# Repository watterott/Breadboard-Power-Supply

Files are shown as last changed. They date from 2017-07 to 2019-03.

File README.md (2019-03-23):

# Breadboard Power Supply
Power supply for Breadboards.

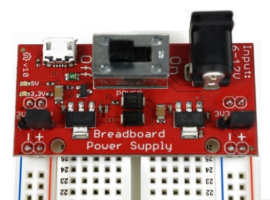
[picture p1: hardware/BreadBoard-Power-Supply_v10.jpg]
Breadboard Power Supply (5V/3.3V)


* Power Input: microUSB or 2.1mm DC jack
* 5V 800mA voltage regulator
* 3.3V 800mA voltage regulator
* 3.3V or 5V output selectable with jumper
* Open-Source and released under the [Creative Commons Attribution Share-Alike License](https://creativecommons.org/licenses/by-sa/4.0/).
* **[Documentation on learn.watterott.com](https://learn.watterott.com)**

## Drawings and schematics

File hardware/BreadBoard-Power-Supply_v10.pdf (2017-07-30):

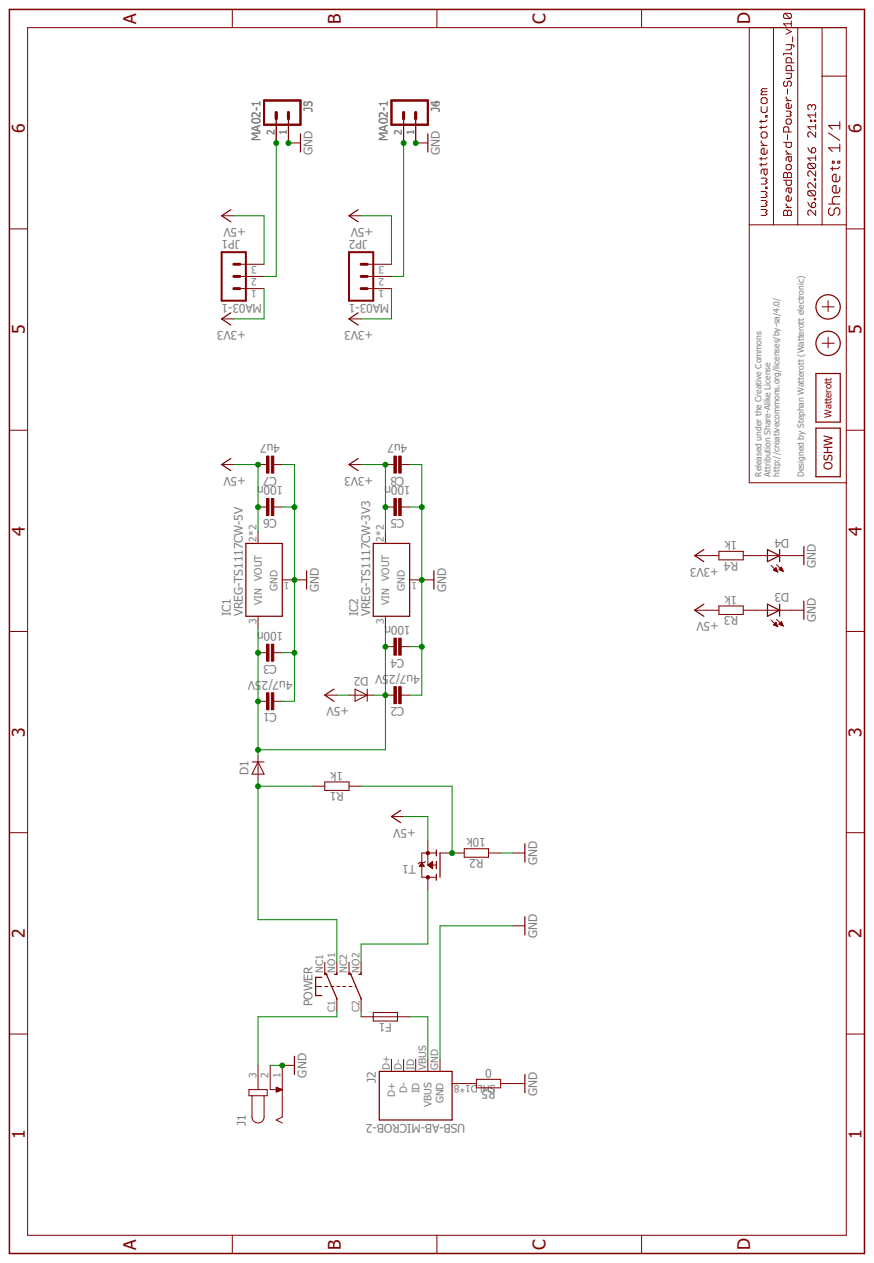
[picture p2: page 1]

VREG-TS1117CW-3V3 VREG-TS1117CW-5V V52/ 7u4 V52/ 7u4 n001 n001 n001 n001 7u4 7u4 V5 + V5 + V5 + 3V3 + 3V3 + 3V3 + GND GND V5 + V5 + k1 k01 GND GND k1k1 3V3 + V5 + GND GND MA02-1 MA02-1 GND GND GND GND 0 1- 30A M 1- 30A M MA02-1 MA02-1 Released under the Creative Commons Attribution Share-Alike License http://creativecommons.org/licenses/by-sa/4.0/ Designed by Stephan Watterott (Watterott electronic) IC2 GND VIN 3 V1 OUT 2*2 IC1 GND VIN 3 V1 OUT 2*2 1C 2C 3C 4C 6C 5C 7C 8C J1 321 D1 D+ D+ D- D- VBUS VBUS GND GND J2 2- BORCI M- BA- BSU8*1DL HS ID ID 1T 1F 2D 1R 2R C1 NO1 NC1 POWER C2 NO2 NC2 3D4D 3R4R J3 21 J4 21 5R 1PJ 123 2PJ 123 J5 21 J6 21 ABCD 1 2 3 4 5 6 ABCD 1 2 3 4 5 6 OSHW Watterott

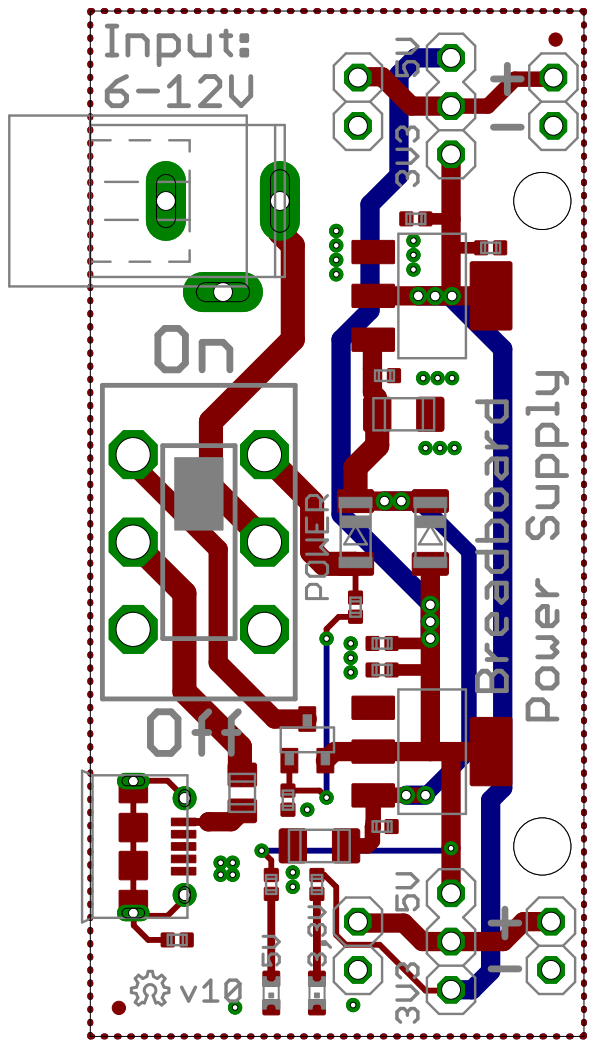
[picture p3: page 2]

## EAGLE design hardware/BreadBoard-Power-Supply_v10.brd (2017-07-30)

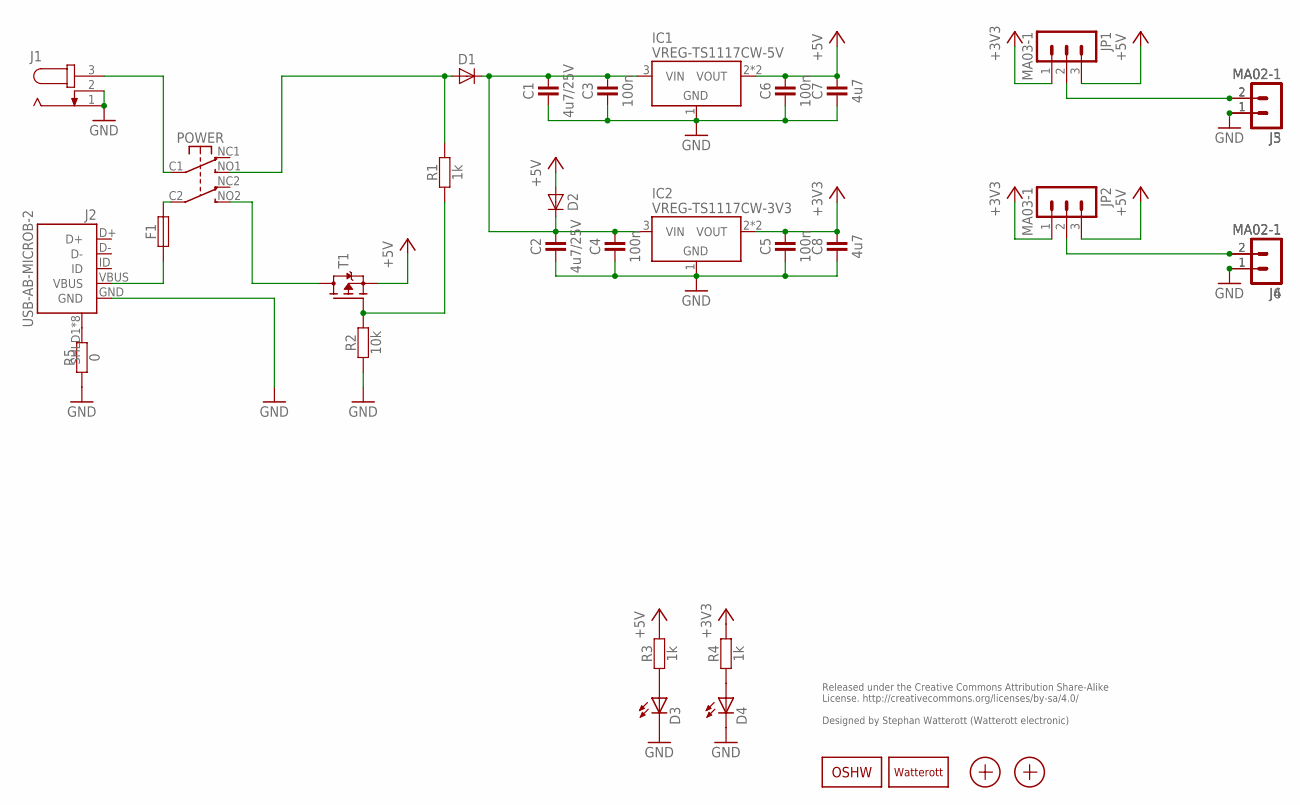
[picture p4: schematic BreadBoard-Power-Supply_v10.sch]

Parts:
C1, C2: 4u7/25V; C1206
C3, C4, C5, C6: 100n; C0402
C7, C8: 4u7; C0402
D1, D2: DIODE-SOD80; SOD80
D3, D4: LED-0603; C0603
F1: FUSE-0805; C0805
IC1: VREG-TS1117CW-5V; SOT223
IC2: VREG-TS1117CW-3V3; SOT223
J1: DC-JACK-2.1; DC-JACK
J2: USB-AB-MICROB-2; USB-MICROB-10118194
J3, J4, J5, J6: MA02-1
JP1, JP2: MA03-1
LOGO1: OSHW_LOGOX0070; OSHW_6X70
LOGO2: LOGO-PLACE; LOGO_TPLACE
POWER: SW-2UMGF1260159; GF1260159
R1, R3, R4: 1k; C0402
R2: 10k; C0402
R5: 0; C0402
T1: MOSFET-P-SOT23; SOT23
X1, X2: PASSER-07; PASSER_07MM

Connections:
+3V3: C5.2, C8.2, IC2.2 (VOUT), IC2.4 (VOUT), JP1.1, JP2.1, R4.2
+5V: C6.2, C7.2, D2.A, IC1.2 (VOUT), IC1.4 (VOUT), JP1.3, JP2.3, R3.2, T1.2 (S)
GND: C1.1, C2.1, C3.1, C4.1, C5.1, C6.1, C7.1, C8.1, D3.C, D4.C, IC1.1 (GND), IC2.1 (GND), J1.1, J1.2, J2.GND, J3.1, J4.1, J5.1, J6.1, R2.1, R5.1
unnamed: D1.A, POWER.NO1 (S1), R1.2
unnamed: J1.3, POWER.C1 (P1)
unnamed: R1.1, R2.2, T1.1 (G)
unnamed: POWER.NO2 (S2), T1.3 (D)
unnamed: D3.A, R3.1
unnamed: D4.A, R4.1
unnamed: J3.2, J5.2, JP1.2
unnamed: J4.2, J6.2, JP2.2
unnamed: F1.2, POWER.C2 (P2)
unnamed: J2.SHLD1 (SHIELD), J2.SHLD2 (SHIELD), J2.SHLD3 (SHIELD), J2.SHLD4 (SHIELD), J2.SHLD5 (SHIELD), J2.SHLD6 (SHIELD), J2.SHLD7 (SHIELD), J2.SHLD8 (SHIELD), R5.2
VBUS: F1.1, J2.VBUS
VIN: C1.2, C2.2, C3.2, C4.2, D1.C, D2.C, IC1.3 (VIN), IC2.3 (VIN)

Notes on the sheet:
Released under the Creative Commons Attribution Share-Alike License. http://creativecommons.org/licenses/by-sa/4.0/ Designed by Stephan Watterott (Watterott electronic)

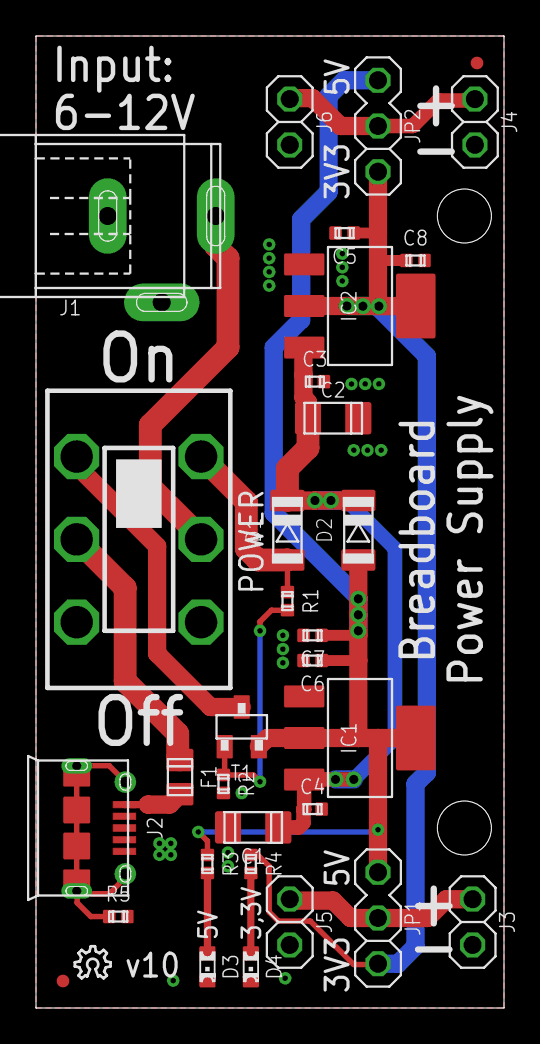
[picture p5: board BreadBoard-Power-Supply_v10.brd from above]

Board: 2 copper layers, 26.0 x 54.0 mm, 34 parts (1 on the bottom side), 15 nets.
